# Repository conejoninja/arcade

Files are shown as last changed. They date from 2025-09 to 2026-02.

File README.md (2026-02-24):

# Gopher ARCADE

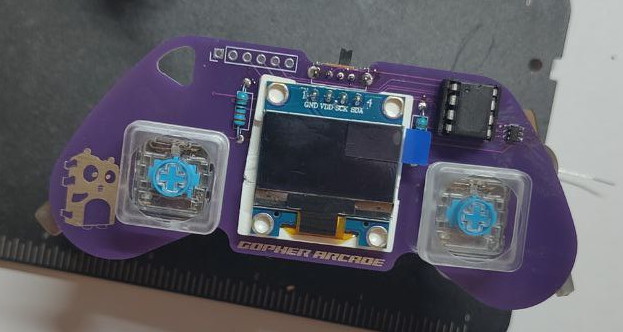
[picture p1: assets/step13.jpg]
Gopher ARCADE


Gopher ARCADE is a simple ATTiny85 game console based on [Armour Grade](github.com/ArmourGrade/Attiny85-Arduino-Game-Console). I wanted to make some modifications and also improve my PCB making skills, so I recreated it from scratch since there were no source files, only gerbers.

There's a good collection of games written in Arduino/C: https://github.com/andyhighnumber/Attiny-Arduino-Games

My idea is to write some games in Go with [TinyGo](https://tinygo.org/)

## Building

While is pretty straight forward to mount all the components, check out the [build guide](BUILD_GUIDE.md) for the easiest order to do so.

## Hardware

In the _hardware/kicad_ folder you could find the KiCAD project with the used mods as well as the gerbers files in case you want to just order some PCBs without modifying them.

### Parts list

| No | Item name | Quantity | Notes |
|----|---|---|---|
| 1  | PCB | 1 | 
| 2  | ATTiny85 20PU | 1 | 
| 3  | DIP8P socket | 1 | 
| 4  | SSD1306 I²C 128x64 display | 1 | 
| 5  | 10k ohm resistors (through hole) | 2 | 
| 6  | SN74LVC2G04DBVR | 1 | 
| 7  | CPT-1203-78-SMT-TR (buzzer) | 1 | 
| 8  | EG1213 switch | 1 | 
| 9  | CR2032 battery holder (smd) | 1 | 
| 10 | Kailh choc v2 low profile | 2 | footprint accepts both kailh choc v1 & v2
| 11 | Kailh choc v2 low profile keycap | 2 | 
| 12 | Display spacer (3d printed) | 1 | optional, but helps aligning the display

## Software

### Code

The _github.com/conejoninja/arcade/tinyssd1306_ package has a simple driver for the display as the once in the [drivers repository](https://github.com/tinygo-org/drivers) has a buffer and doesn't fit in the **ATTiny85**.

Board's pins are defined as follows:

```go
const (
	P5 Pin = PB0
	P6 Pin = PB1
	P7 Pin = PB2
	P2 Pin = PB3
	P3 Pin = PB4
	P1 Pin = PB5

	LED          = P1
	BUTTON_LEFT  = P7
	BUTTON_RIGHT = P5
	SPEAKER      = P6
)
```

## Flashing

### Requirements 

You need TinyGo and [avrdude](https://github.com/avrdudes/avrdude). Depending on your OS, you can check the [installation instructions](https://tinygo.org/getting-started/install/).

### Connecting

Here you could find how to connect it to your USBasp probe.

You could use the 10-Pin connector to the ATTiny85:
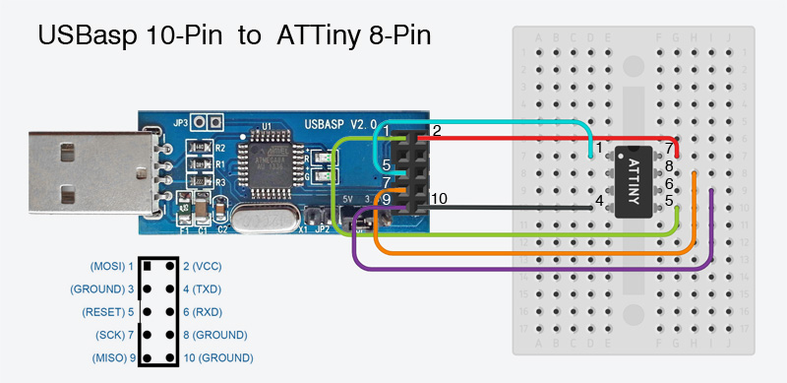
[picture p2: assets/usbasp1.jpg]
10Pin


You could use the 6-Pin connector to the ATTiny85:
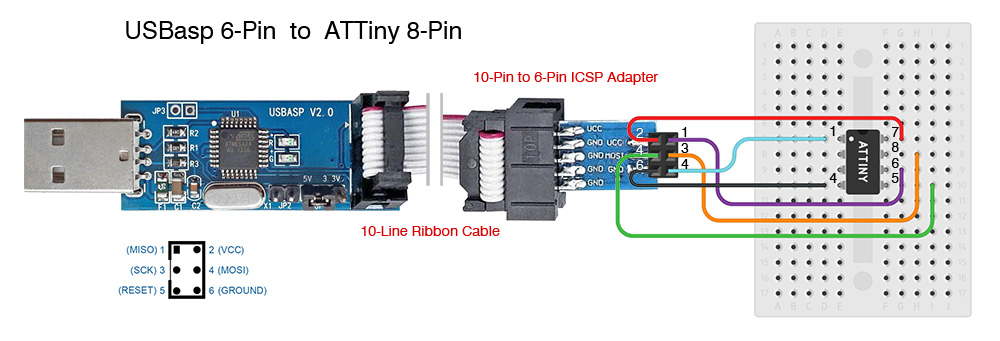
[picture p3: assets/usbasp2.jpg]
6Pin


Or if you don't want to take out/in the chip each time (you could damage the pins of the ATTiny), you could connect to the board directly as follows:
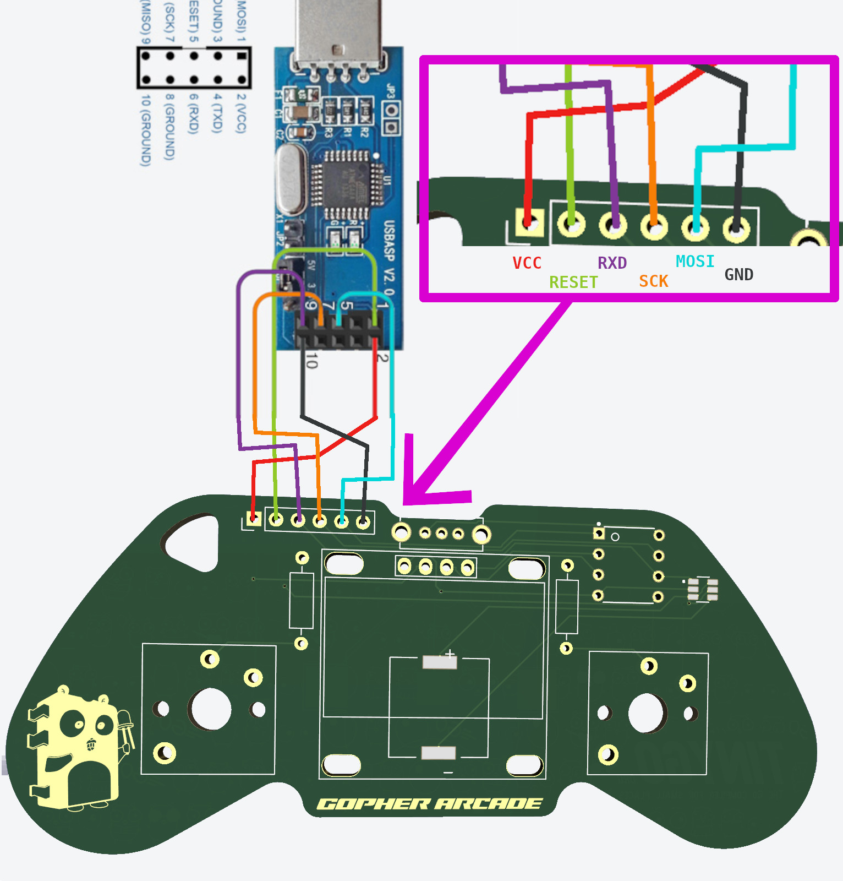
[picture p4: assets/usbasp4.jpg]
Directly to the board


### Flashing

By default the ATTiny85 runs at 1MHz, you can make it runs at 8MHz with the following command **(this is only required once)**.

```bash
avrdude -p attiny85 -c usbasp -B 32 -U lfuse:w:0xE2:m
```

You could use [TinyGo](https://tinygo.org/) with USBASP and the target _gopher-arcade_ to flash it as follows:

```bash
tinygo flash -size=short -target gopher-arcade  .
```

### Not TinyGo
There's a good collection of games written in Arduino/C: https://github.com/andyhighnumber/Attiny-Arduino-Games 

 Note: some of then need a different board with analog input or more buttons. 

 Unfortunately I can not provide support on how to flash them (use the Arduino IDE *\*wink \*wink*) as it defeats the purpose of programming them with TinyGo!

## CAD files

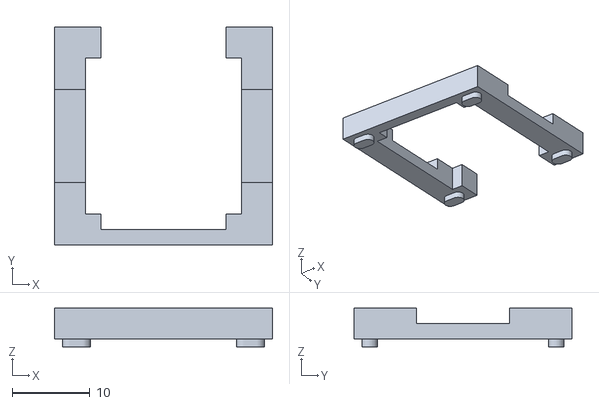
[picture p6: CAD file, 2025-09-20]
hardware/3D/display_spacer.STL
28.0 x 28.0 x 5.00

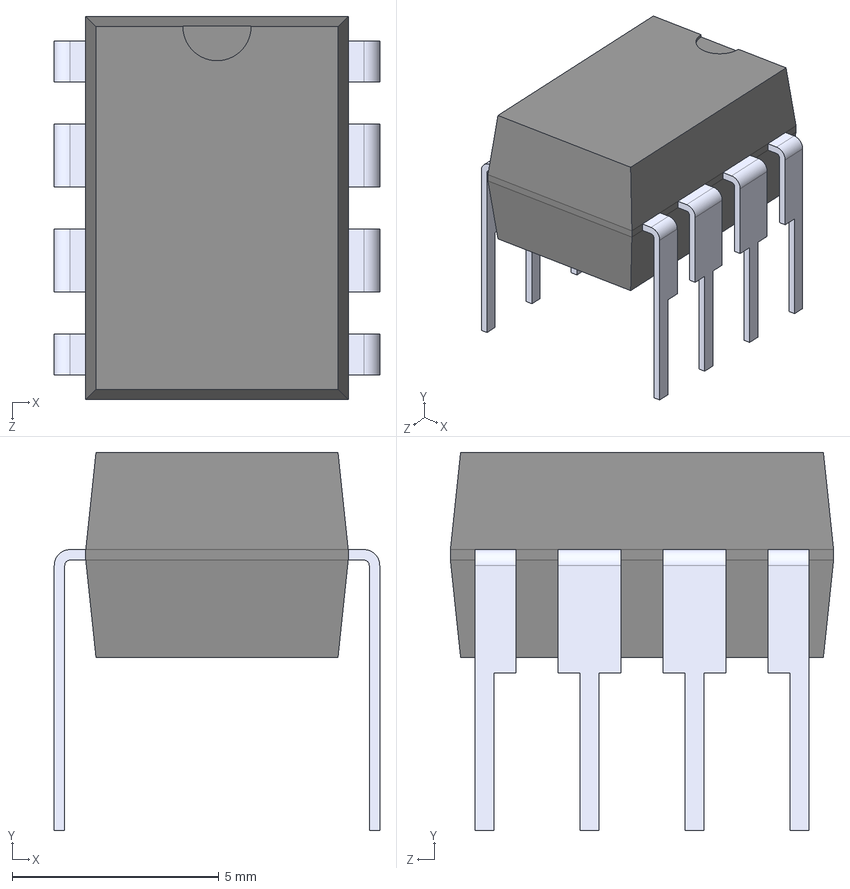
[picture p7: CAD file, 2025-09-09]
hardware/kicad/mods/ATTINY85-20PU.step
7.87 x 9.14 x 9.27 mm

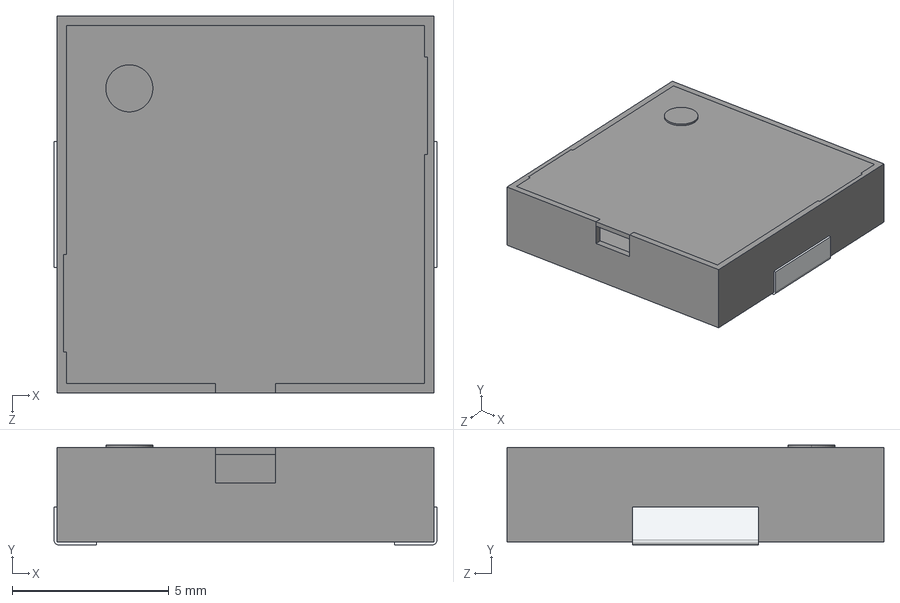
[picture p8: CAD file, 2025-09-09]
hardware/kicad/mods/CPT-1203-78-SMT-TR.step
12.2 x 3.18 x 12.0 mm

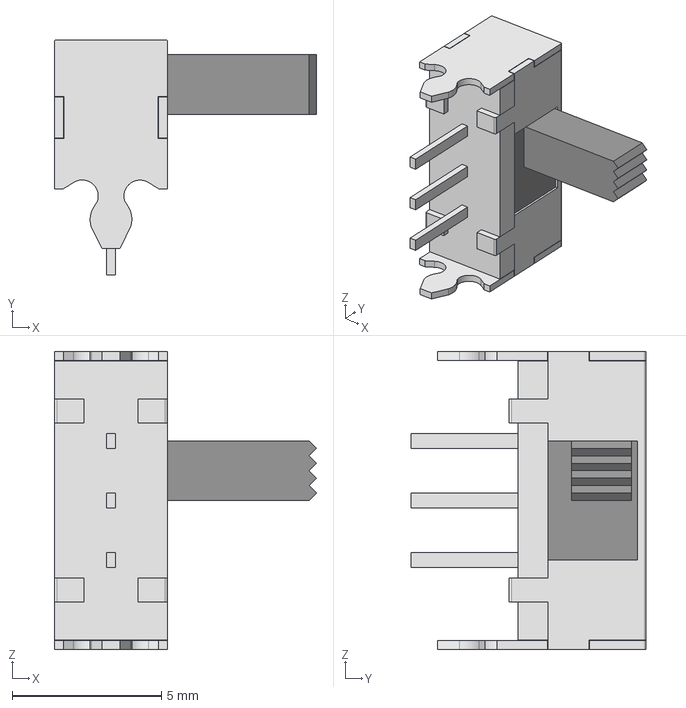
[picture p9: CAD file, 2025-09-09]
hardware/kicad/mods/EG1213.step
8.80 x 7.90 x 10.00 mm

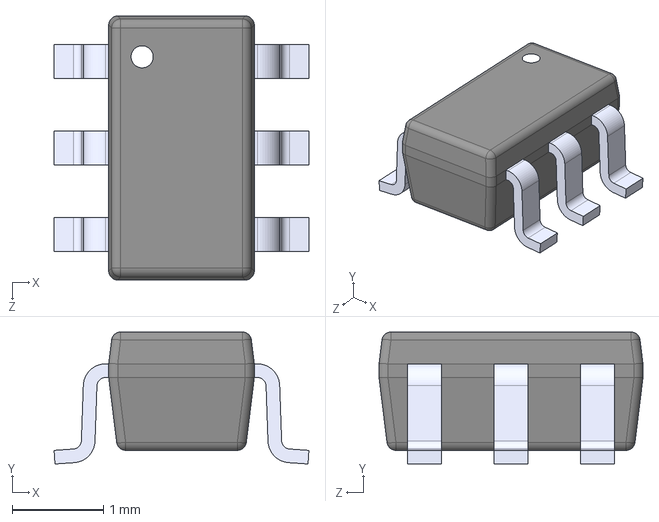
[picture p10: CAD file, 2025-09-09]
hardware/kicad/mods/SN74LVC2G04DBVR.step
2.80 x 1.45 x 2.90 mm

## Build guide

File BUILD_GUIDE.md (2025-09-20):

# Build guide

For building Gopher ARCADE you need an iron solder and some solder. Flux is highly recommended too (specially for the SN74LVC2G04DBVR). We recommend you do it in a well ventilated room and with the proper safety precautions.

## Parts list

| No | Item name | Quantity | Notes |
|----|---|---|---|
| 1  | PCB | 1 | 
| 2  | ATTiny85 20PU | 1 | 
| 3  | DIP8P socket | 1 | 
| 4  | SSD1306 I²C 128x64 display | 1 | 
| 5  | 10k ohm resistors (through hole) | 2 | 
| 6  | SN74LVC2G04DBVR | 1 | 
| 7  | CPT-1203-78-SMT-TR (buzzer) | 1 | 
| 8  | EG1213 switch | 1 | 
| 9  | CR2032 battery holder (smd) | 1 | 
| 10 | Kailh choc v2 low profile | 2 | footprint accepts both kailh choc v1 & v2
| 11 | Kailh choc v2 low profile keycap | 2 | 
| 12 | Display spacer (3d printed) | 1 | optional, but helps aligning the display

## Component descriptions

### PCB

On the left of the image is the top part of the PCB and on the right is the bottom side.

## Front side
We'll use this badge to indicate the orientation during assembly: 

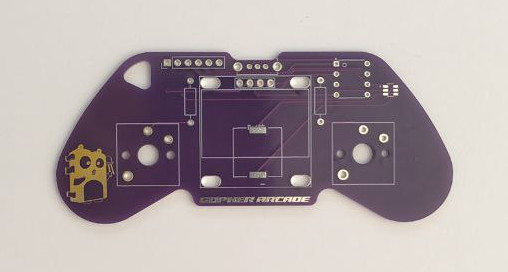
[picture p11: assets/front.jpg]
Front side


## Back side
We'll use this badge to indicate the orientation during assembly: 

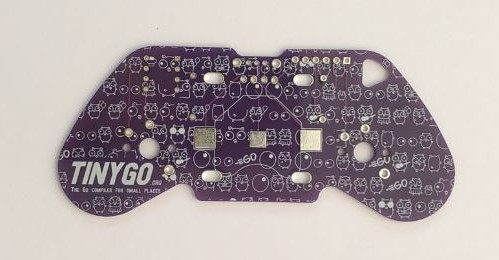
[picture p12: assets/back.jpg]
Back side


# Soldering/assembly

The following describes soldering and assembly.
For each item, some work on the front side and some work on the back side.
The badge below indicates the orientation at the start of work, so please refer to it. 



We need to prepare the board for the two SMD components, the buzzer in the middle of the board and the tiny SN74LVC2G04DBVR on the top right corner. Add a little bit of flux (if you have it) and solder on the circled areas of the image. Let's start with the SN74LVC2G04DBVR as it's the most difficult component.

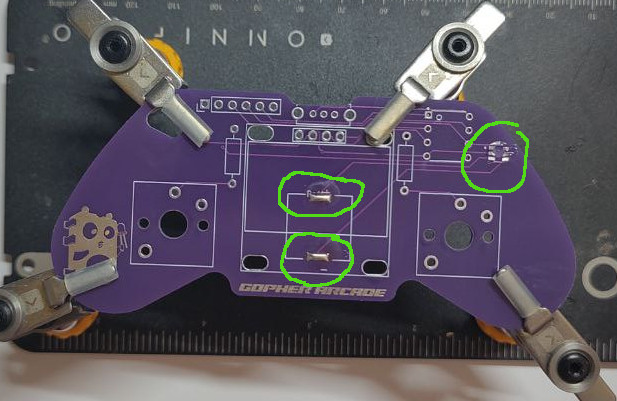
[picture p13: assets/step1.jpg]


Check the orientation, as the dot in the SN74LVC2G04DBVR should match the dot on the PCB as the following image:
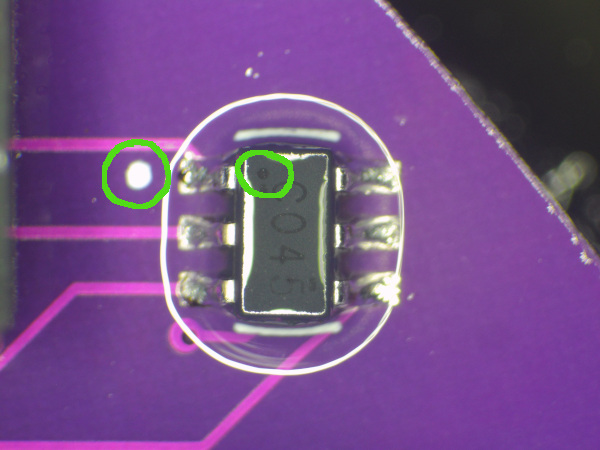
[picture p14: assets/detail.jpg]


Once the board has some solder on the pads, place the component on top of it and press it down with some tweezers. Heat one side of the SN74LVC2G04DBVR with the iron, heat the other side. Check there are no shortcircuits among the pads.

Next you can do the resitors, resistors don't have orientation.

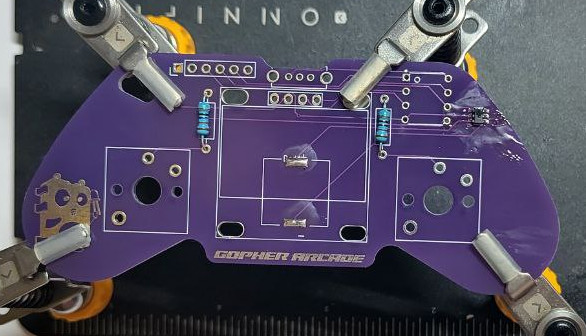
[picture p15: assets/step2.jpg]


Now we can do the buzzer, check the orientation, the dot should be on the top right corner. We do the same procedure as with the SN74LVC2G04DBVR, place the buzzer on top of the pre-soldered pad. Heat one side and then the other. 

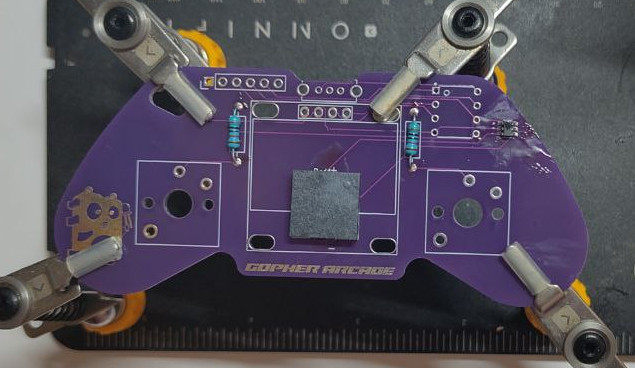
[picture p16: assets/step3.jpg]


Now on the back side we need to fit the switch on the  but we solder the pins on the 

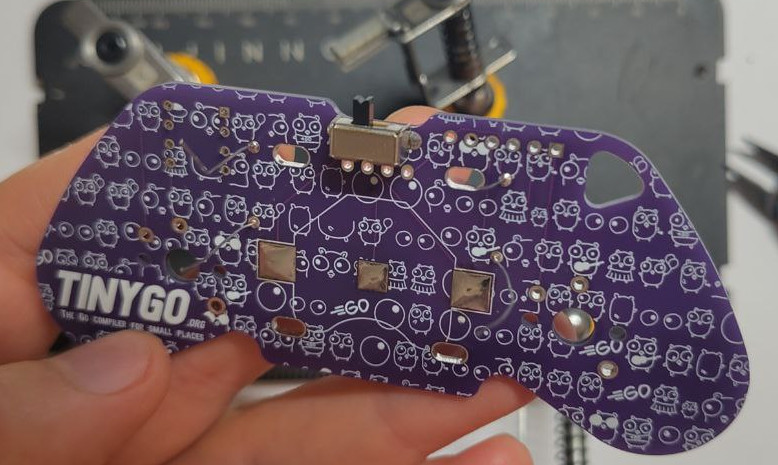
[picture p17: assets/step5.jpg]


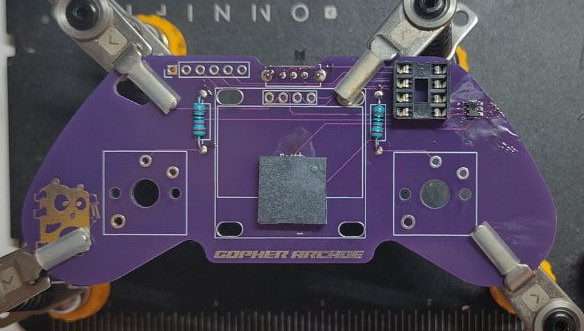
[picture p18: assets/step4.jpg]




With the DIP8P socket is the contrary, we put it on the  and solder on the . Check the orientation.

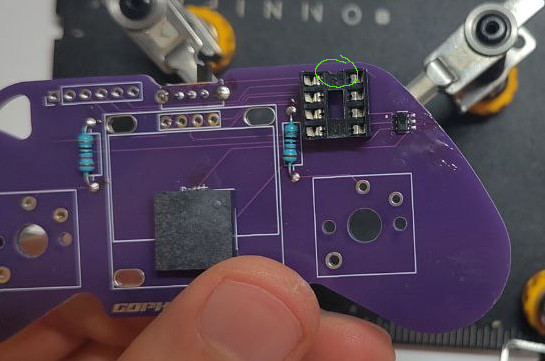
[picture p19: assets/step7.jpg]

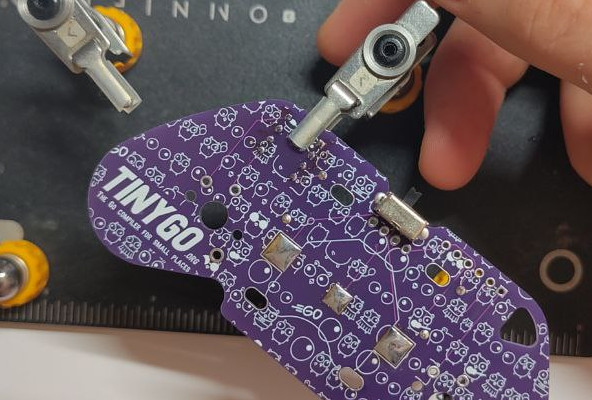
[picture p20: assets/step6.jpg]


Follow with the key switches. Both Kailh choc v1 or v2 are compatible. Use some clips to hold the switches if needed, or maybe some tape or some removable adhesive putty.

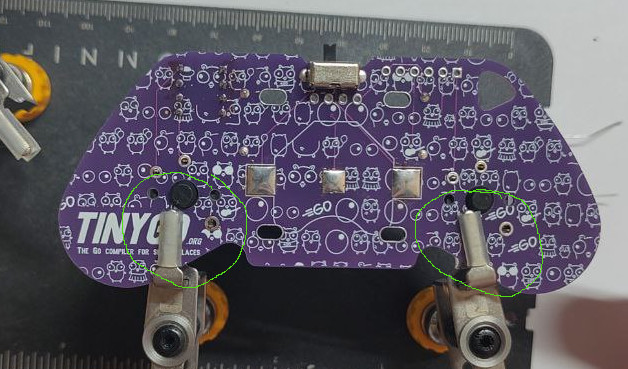
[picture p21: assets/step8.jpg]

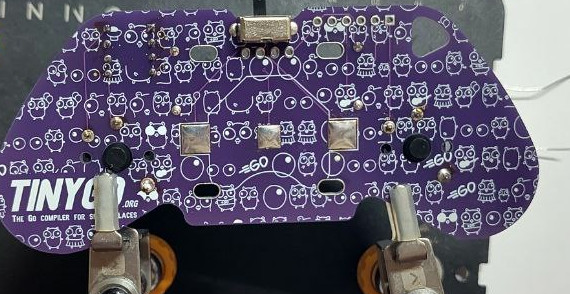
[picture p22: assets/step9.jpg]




Place the display spacer on the front as shown in the following image. Place the display too, hold it with some clips, adhesive putty or tape.

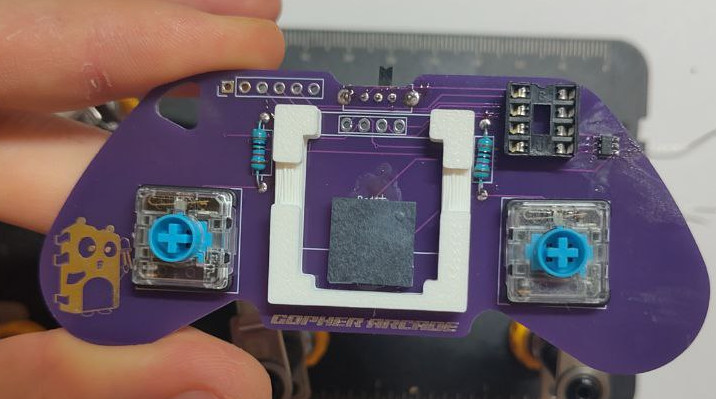
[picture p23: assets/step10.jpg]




Solder the 4 pins of the display.

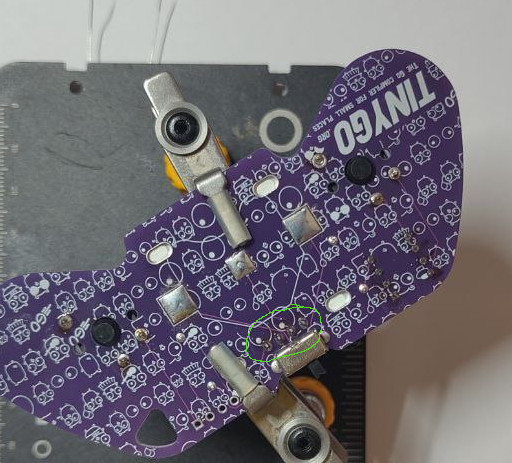
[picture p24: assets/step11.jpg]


The last step is to solder the battery holder. Add some solder to the three pads. A little bump in the middle will help the contact with the battery. Press the battery holder against the PCB and heat each one of the pads on the sides until the tin melts and keep the holder in place.

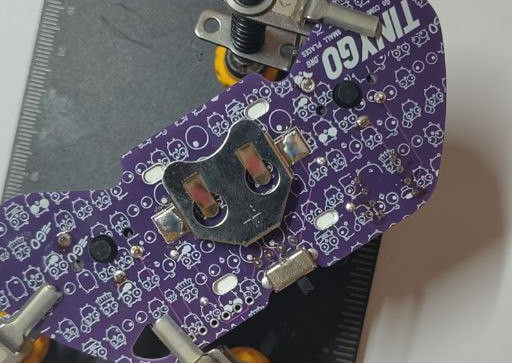
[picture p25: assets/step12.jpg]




Add the keycaps, the ATTiny85 on the socket and it's done! Congratulations on your new **Gopher ARCADE**

Gopher ARCADE

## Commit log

2025-09-11 organize hardware folder
    [ATTINY85-20PU.step, CPT-1203-78-SMT-TR.step, EG1213.step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]
2025-09-11 better STL
    [display_spacer.STL]
2025-09-20 added build guide
    [display_spacer.STL]
